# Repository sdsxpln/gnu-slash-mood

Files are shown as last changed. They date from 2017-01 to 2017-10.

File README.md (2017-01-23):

GNU/Mood: An IoT mood indicator for GNU Social
==============================================

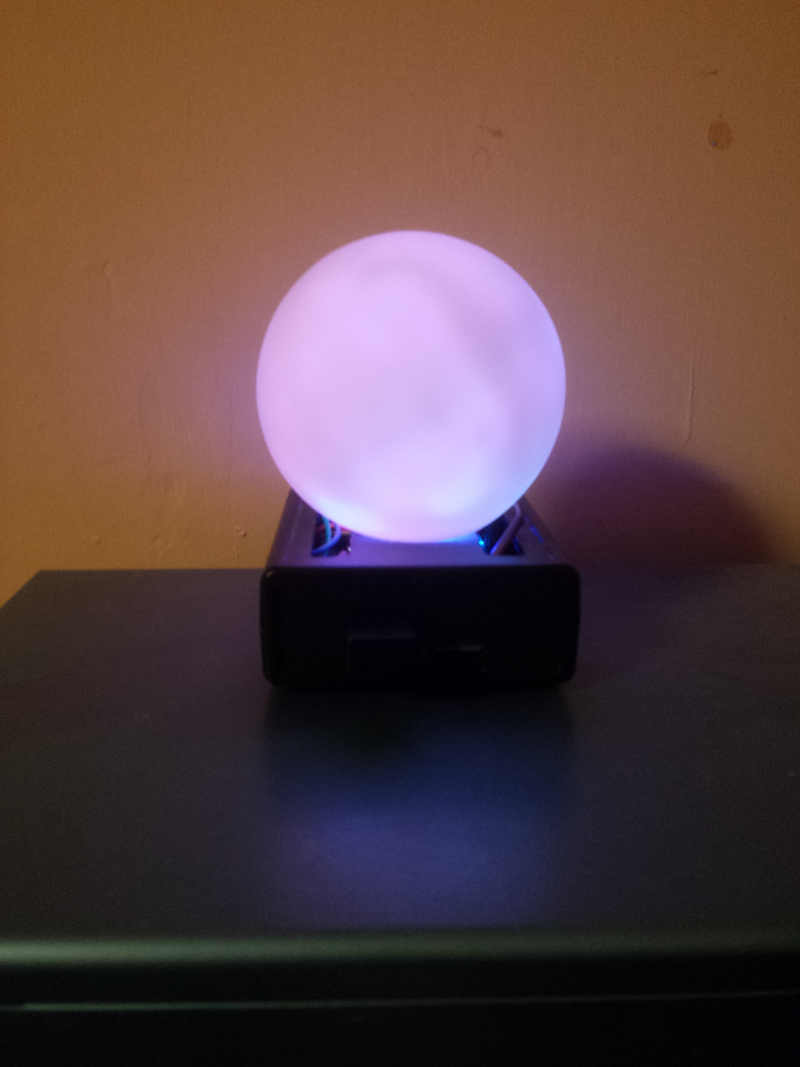
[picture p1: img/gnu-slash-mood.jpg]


GNU/Mood is a mood ball hack where the colour LEDs are controlled by sentiment analysis of your GNU Social timeline. It reads the last few entries in your timeline and extracts three mood dimensions:

 - Egocentrism: Talk about yourself versus talk about others
 - Valence: An indicator of positive or negative affect. Happyness or sadness.
 - Gender: Feminine or masculine related words or names

These measures are then turned into LED illumination values to produce the colour of the ball, which changes slowly and almost imperceptibly.

GNU/Mood can also be "triggered" if it detects certain key words within the timeline. This causes it to pulsate slowly and soothingly, guiding the user into a more blissful state of mind.

Bill of Materials
=================

    1 x Beaglebone Black (wireless or with a compatible wifi dongle)
    1 x Beaglebone Black case (Choose your favourite or 3D print one)
    1 x micro/mini USB cable (the type which usually comes with a Beaglebone Black)
    1 x 5V 2A power supply for the Beaglebone Black
    6 x Dupont Cables male to female Jumper GPIO Wire Ribbon
    1 x Ultrabright 3V red LED
    1 x Ultrabright 3V green LED
    1 x Ultrabright 3V blue LED
    1 x LED Mood Ball Lamp
    1 x microSD card (8GB or larger, class 10)
    1 x Small amount of bubble wrap packing plastic
    1 x Superglue

Tools
=====

    Precision screwdrivers
    Junior hacksaw
    Pliers
    Drill

Wiring
======

Connecting the LEDs to the Beaglebone Black is very simple and no resistors should be needed. You can either solder the LEDs to the dupont cables, or just inserting them into the female sockets is usually good enough.

    Red    P8/13
    Green  P9/14
    Blue   P8/19

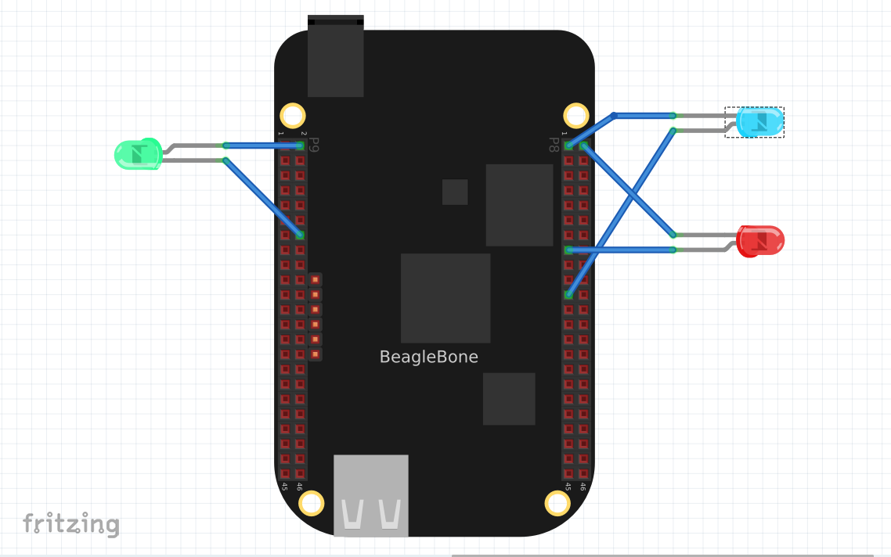
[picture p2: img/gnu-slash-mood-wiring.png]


Preparing the Mood Ball
=======================

Use a precision screwdriver to remove the batteries from the Mood ball.



With a junior hacksaw cut around the bottom of the mood ball to loosen the electronics section. Make sure not to scratch the surface of the rest of the ball. Once it's loose enough it can be carefully pulled out with pliers.



The existing electronics aren't needed, but you may wish to salvage the LEDs from it by desoldering them. For an easy life, just use new LEDs if you have them available. They should be the ultra bright type and any physical size will do.

Installing the Software
=======================

The Beaglebone Black comes with an existing operating system installed, but the 4GB onboard flash storage may not be enough for the new software and so it's better to install the operating system onto a microSD card instead.

Download the latest [Debian firmware image](http://beagleboard.org/latest-images) and copy it to the microSD card. The command will be something like:

``` bash
sudo dd if=[image filename] of=/dev/sdX
sync
```

Where *sdX* is the microSD drive on your laptop/desktop. You can find out what this should be just by removing the microSD card then running:

``` bash
ls /dev/sd*
```

Then inserting the microSD card and running the same command again. Typically this will be *sdb*, *sdc*, *sdd*, etc. Once that has coppied insert the card into the Beaglebone Black and connect it to your laptop/desktop with the USB cable. If you're using an external wifi dongle then also plug that into the Beaglebone Black. After a few minutes you will then be able to ssh into the Beaglebone Black with:

``` bash
ssh debian@192.168.7.2
```

The initial temporary password is usually *temppwd*. Change it with the command:

``` bash
passwd
```

Then set up the wifi connection with:

``` bash
sudo connmanctl
connmanctl> technologies
connmanctl> tether wifi disable
connmanctl> enable wifi
connmanctl> scan wifi
connmanctl> services
connmanctl> agent on
connmanctl> connect wifi_[somenumbers]
connmanctl> quit
```

If the connect command worked then your Beaglebone is now ready for wireless operation. Disconnect the USB cable and plug in the external 5V power supply. After a few minutes once it has booted again you can ssh back into it with:

``` bash
ssh debian@beaglebone.local
```

Note that you will need to have avahi/mDNS configured on your system to be able to do this. Now run:

``` bash
sudo apt-get update
sudo apt-get upgrade
sudo apt-get -y install build-essential git curl libcurl4-openssl-dev ntp
git clone https://github.com/bashrc/libbbb
git clone https://github.com/bashrc/libgnusocial
git clone https://github.com/bashrc/gnu-slash-mood
cd libbbb
make
sudo make install
cd ../libgnusocial
make
sudo make install
cd ../gnu-slash-mood
make
sudo make install
sudo cp daemons/gnu-slash-mood.service /etc/systemd/system
sudo mkdir /var/lib/gnu-slash-mood
sudo nano /var/lib/gnu-slash-mood/config.txt
```

Add the following, setting your details as needed. The *off* and *on* values are the hours of the day when GNU/Mood should turn off and then turn on again so as not to disturb sleep (0 is midnight).

    username = [myusername]
    password = [password]
    domain = [GNU Social domain]
    off = 0
    on = 7

Now enable the daemon:

``` bash
sudo systemctl enable gnu-slash-mood
sudo systemctl start gnu-slash-mood
```

You can check that the daemon started correctly with:

``` bash
sudo systemctl status gnu-slash-mood -l
```

Once the software is running you should see that the LEDs initially flash and then transition to a stable colour.

Final Assembly
==============

Mount the Beaglebone Black into its case. Usually it's fastened down with four screws.

Drill three (or as many as needed) holes into the top of the case so that the LEDs can poke through. One possible way to do it is with six small holes which then fit the LED terminals.

Scrumple up the bubble wrap and put it inside the mood ball. The bubbles will cause light from the LEDs to be diffracted in all directions, giving a more uniform colour and avoiding any isolated spots of colour.

Fit the top of the case to the bottom, then place the mood ball over the LEDs. Check that it illuminates as expected.

Glue the mood ball to the top of the case with some superglue.

GNU/Mood is now ready for moodyness.

Security Tips
=============

Everyone is paranoid about the *internet of hopelessly insecure things*. To improve the security of GNU/Mood you can do the following:

``` bash
ssh debian@beaglebone.local
sudo nano /etc/ssh/sshd_config
```

Set the following:

    PermitRootLogin no
    PermitEmptyPasswords no

And if you are using *~/.ssh/authorized_keys* then set:

    PasswordAuthentication no

Save and reboot the Beaglebone.

Custom Trigger Words
====================

You can customise the words which cause GNU/Mood to pulsate.

``` bash
ssh debian@beaglebone.local
sudo nano /var/lib/gnu-slash-mood/triggers.txt
```

An example *triggers.txt* file might look like:

``` text
stallman
systemd
DRM
#NSFW
proprietary
```

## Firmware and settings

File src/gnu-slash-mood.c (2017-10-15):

/*
    GNU/Mood: A mood indicator for GNU Social
    Copyright (C) 2017 Bob Mottram
    bob@freedombone.net

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
    You should have received a copy of the GNU General Public License
    along with this program.  If not, see <http://www.gnu.org/licenses/>.
*/

#include <time.h>
#include "gnu-slash-mood.h"

/* The maximum number of characters obtained from the timeline */
#define MAX_TEXT_LENGTH    (1024*4)

/* Check the timeline every few minutes */
#define CHECK_TIMELINE_SEC (60 * 5)

/* whether to show a test pattern */
unsigned char use_test_pattern = 0;

/* whether to enable debugging output */
unsigned char debug = 0;

/* login details */
char gnusocial_username[512];
char gnusocial_password[512];
char gnusocial_domain_name[512];

/* time to turn off and on again */
unsigned char hour_off = 0;
unsigned char hour_on = 7;

struct gss_account acc;

/**
 * @brief Show help
 */
void show_help()
{
    printf("\nGNU/Mood: The mood of the community\n\n");
    printf("Pinout: Red P8/13, Green P9/14, Blue P8/19\n\n");
    printf(" -h --help              Show help\n");
    printf(" -u --username [name]   Username\n");
    printf(" -d --domain [name]     Site domain name\n");
    printf(" -p --password [text]   Password\n\n");
    printf(" -t --test              Test mode\n");
    printf(" -c --config [filename] Read login details from file\n");
    printf("    --off [hour]        Hour when to turn off\n");
    printf("    --on [hour]         Hour when to turn on\n");
    printf("    --debug             Enable debugging output\n\n");
}

/**
 * @brief Returns 1 if the mood ball should be active
 */
int is_active()
{
    int state = 1;
    time_t t = time(NULL);
    struct tm *tmp = gmtime(&t);

    if (hour_off > hour_on) {
        if ((int)tmp->tm_hour > (int)hour_off)
            state = 0;
        if ((int)tmp->tm_hour < (int)hour_on)
            state = 0;
    }
    else {
        if (((int)tmp->tm_hour >= (int)hour_off) &&
            ((int)tmp->tm_hour < (int)hour_on))
            state = 0;
    }

    return state;
}

/**
 * @brief Reads an individual line from the config file
 * @param linestr The line of text
 * @param Returned parameter value
 * @return Zero on success
 */
int read_login_param(char * linestr, char * paramstr)
{
    int i, j;

    for (i = 0; i < strlen(linestr); i++) {
        if ((linestr[i] == '=') || (linestr[i] == ':')) break;
    }

    if (i == strlen(linestr))
        return 1;

    /* skip any spaces or tabs */
    i++;
    while (((linestr[i] == ' ') || (linestr[i] == '\t')) &&
           (i < strlen(linestr)-1))
        i++;

    j = 0;
    while (i < strlen(linestr)) {
        if ((linestr[i] != 10) && (linestr[i] != 13))
            paramstr[j++] = linestr[i];
        i++;
    }
    paramstr[j] = 0;

    return 0;
}

int read_login_credentials(char * config_filename)
{
    FILE * fp;
    char linestr[512], paramstr[512];

    /* clear login credentials */
    gnusocial_username[0] = 0;
    gnusocial_password[0] = 0;
    gnusocial_domain_name[0] = 0;

    fp = fopen(config_filename, "r");
    if (!fp) return 1;

    while (!feof(fp)) {
        if (fgets(linestr , 511 , fp) != NULL ) {
            if (strlen(linestr) == 0) continue;
            if (linestr[0] == '#') continue;

            linestr[0] = tolower(linestr[0]);
            if ((strstr(linestr,"username =") != NULL) ||
                (strstr(linestr,"username :") != NULL) ||
                (strstr(linestr,"username:") != NULL) ||
                (strstr(linestr,"username=") != NULL)) {
                if (read_login_param(linestr, paramstr) != 0)
                    return 2;
                sprintf(gnusocial_username, "%s", paramstr);
            }

            if ((strstr(linestr,"password =") != NULL) ||
                (strstr(linestr,"password :") != NULL) ||
                (strstr(linestr,"password:") != NULL) ||
                (strstr(linestr,"password=") != NULL)) {
                if (read_login_param(linestr, paramstr) != 0)
                    return 3;
                sprintf(gnusocial_password, "%s", paramstr);
            }

            if ((strstr(linestr,"domain =") != NULL) ||
                (strstr(linestr,"domain :") != NULL) ||
                (strstr(linestr,"domain:") != NULL) ||
                (strstr(linestr,"domain=") != NULL)) {
                if (read_login_param(linestr, paramstr) != 0)
                    return 4;
                sprintf(gnusocial_domain_name, "%s", paramstr);
            }

            if ((strstr(linestr,"off =") != NULL) ||
                (strstr(linestr,"off :") != NULL) ||
                (strstr(linestr,"off:") != NULL) ||
                (strstr(linestr,"off=") != NULL)) {
                if (read_login_param(linestr, paramstr) != 0)
                    return 5;
                hour_off = (unsigned char)atoi(paramstr);
            }

            if ((strstr(linestr,"on =") != NULL) ||
                (strstr(linestr,"on :") != NULL) ||
                (strstr(linestr,"on:") != NULL) ||
                (strstr(linestr,"on=") != NULL)) {
                if (read_login_param(linestr, paramstr) != 0)
                    return 6;
                hour_on = (unsigned char)atoi(paramstr);
            }
        }
    }

    fclose(fp);

    if ((strlen(gnusocial_username) == 0) ||
        (strlen(gnusocial_password) == 0) ||
        (strlen(gnusocial_domain_name) == 0))
        return 7;

    return 0;
}

int set_leds(int r, int g, int b)
{
    if (pwm_output(P8, 13, r) != 0) return 1;
    if (pwm_output(P9, 14, g) != 0) return 2;
    if (pwm_output(P8, 19, b) != 0) return 3;
    return 0;
}

int get_timeline_text(char * text)
{
    struct status * posts;
    const int no_of_posts = 5;
    int i, j, ctr=0;

    if (verify_account(acc) == -1) return 1;
    posts = read_timeline(acc, HOME_TIMELINE, no_of_posts);
    for (i = 0; i < no_of_posts; i++) {
        for (j = 0; j < strlen(posts[i].text); j++) {
            if (ctr >= MAX_TEXT_LENGTH-1) {
                text[ctr]=0;
                return 0;
            }
            text[ctr++] = posts[i].text[j];
        }
        text[ctr++] = '.';
    }
    text[ctr]=0;
    return 0;
}

int mood_loop()
{
    int curr_r=0, curr_g=0, curr_b=0;
    int target_r, target_g, target_b, frequency = 0;
    int ctr_msec=0, phase = 0, intensity = 100, state = 0;
    char text[MAX_TEXT_LENGTH];

    if (get_timeline_text(text) != 0) {
        printf("Failed to grab text from the timeline\n");
        return 1;
    }

    printf("GNU Social login success\n");

    if (use_test_pattern == 0) {
        sentiment_to_rgb(text, &curr_r, &curr_g, &curr_b, &frequency);
        target_r = curr_r;
        target_g = curr_g;
        target_b = curr_b;
    }
    else
        printf("Running test pattern\n");

    if (set_leds(curr_r, curr_g, curr_b) != 0) {
        printf("Unable to set LED pwm values\n");
        return 2;
    }

    while(1) {
        if (is_active() == 0) {
            /* fade out */
            target_r = 0;
            target_g = 0;
            target_b = 0;
        }

        /* shift the colour towards the target */
        if (target_r > curr_r) curr_r++;
        if (target_g > curr_g) curr_g++;
        if (target_b > curr_b) curr_b++;

        if (target_r < curr_r) curr_r--;
        if (target_g < curr_g) curr_g--;
        if (target_b < curr_b) curr_b--;

        if (use_test_pattern != 0) {
            if (curr_r < 1000)
                curr_r += 100;
            else
                if (curr_b < 1000)
                    curr_b += 100;
                else
                    if (curr_g < 1000)
                        curr_g += 100;
                    else {
                        curr_r = 0;
                        curr_b = 0;
                        curr_g = 0;
                    }
        }

        if (debug != 0)
            printf("Active: %d  Colour: %d %d %d  Intensity: %d  Frequency: %d\n",
                   is_active(), curr_r, curr_g, curr_b, intensity, frequency);

        if (set_leds(curr_r*intensity/100,
                     curr_g*intensity/100,
                     curr_b*intensity/100) != 0) {
            printf("Unable to set LED pwm values\n");
        }

        if (ctr_msec >= CHECK_TIMELINE_SEC*1000) {
            ctr_msec = 0;

            if (is_active() == 1) {
                /* update the timeline */
                if (get_timeline_text(text) != 0) {
                    printf("Failed to grab text from the timeline\n");
                }
                else {
                    /* calculate the new target colour */
                    sentiment_to_rgb(text, &target_r, &target_g, &target_b, &frequency);
                    if (debug != 0)
                        printf(">>>> Updated from timeline <<<<\n");
                }
            }
        }

        /* wait */
        usleep(1000*100);
        fflush(stdout);

        ctr_msec += 100;
        if (frequency != 0) {
            if (state == 0) {
                intensity -= 70/(frequency/2);
                if (phase > frequency/2) {
                    state = 1;
                }
            }
            else {
                intensity += 70/(frequency/2);
                if (phase > frequency) {
                    state = 0;
                    phase = 0;
                    intensity = 100;
                }
            }
            if (intensity > 100) intensity = 100;
            if (intensity < 30) intensity = 30;
            phase++;
        }
        else {
            intensity = 100;
            phase = 0;
            state = 0;
        }
    }
    return 0;
}

int main(int argc, char *argv[])
{
    int i;
    char username[1024], domain_name[1024], password[1024];

    /* clear login values */
    username[0] = 0;
    domain_name[0] = 0;
    password[0] = 0;

    /* parse the arguments */
    for (i = 1; i < argc; i++) {
        if (i < argc-1) {
            if ((strcmp(argv[i], "-u") == 0) ||
                (strcmp(argv[i], "--user") == 0) ||
                (strcmp(argv[i], "--username") == 0)) {
                sprintf(username, "%s", argv[i+1]);
                i++;
                continue;
            }

            if ((strcmp(argv[i], "-d") == 0) ||
                (strcmp(argv[i], "--domain") == 0) ||
                (strcmp(argv[i], "--domainname") == 0)) {
                sprintf(domain_name, "%s", argv[i+1]);
                i++;
                continue;
            }

            if ((strcmp(argv[i], "-p") == 0) ||
                (strcmp(argv[i], "--password") == 0) ||
                (strcmp(argv[i], "--passphrase") == 0)) {
                sprintf(password, "%s", argv[i+1]);
                i++;
                continue;
            }

            if ((strcmp(argv[i], "-c") == 0) ||
                (strcmp(argv[i], "--config") == 0)) {
                if (read_login_credentials(argv[i+1]) == 0) {
                    sprintf(username, "%s", gnusocial_username);
                    sprintf(password, "%s", gnusocial_password);
                    sprintf(domain_name, "%s", gnusocial_domain_name);
                }
                else {
                    printf("Invalid configuration file\n");
                    return 4;
                }
                i++;
                continue;
            }

            if (strcmp(argv[i], "--off") == 0) {
                hour_off = (unsigned char)atoi(argv[i+1]);
                i++;
                continue;
            }

            if (strcmp(argv[i], "--on") == 0) {
                hour_on = (unsigned char)atoi(argv[i+1]);
                i++;
                continue;
            }
        }

        if ((strcmp(argv[i], "-h") == 0) ||
            (strcmp(argv[i], "--help") == 0)) {
            show_help();
            return 0;
        }

        if ((strcmp(argv[i], "-t") == 0) ||
            (strcmp(argv[i], "--test") == 0))
            use_test_pattern = 1;

        if (strcmp(argv[i], "--debug") == 0)
            debug = 1;
    }

    if (argc <= 1) {
        show_help();
        return 0;
    }

    if (strlen(username) == 0) {
        printf("Please specify a GNU Social username\n");
        return 1;
    }
    if (strlen(domain_name) == 0) {
        printf("Please specify a GNU Social domain name\n");
        return 2;
    }
    if (strlen(password) == 0) {
        printf("Please specify a GNU Social password\n");
        return 3;
    }

    init_account(&acc, "https", (char*)username, (char*)domain_name, (char*)password);
    mood_loop();

    return 0;
}

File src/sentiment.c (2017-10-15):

/*
  GNU/Mood: A mood indicator for GNU Social
  Copyright (C) 2017 Bob Mottram
  bob@freedombone.net

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
  You should have received a copy of the GNU General Public License
  along with this program.  If not, see <http://www.gnu.org/licenses/>.
*/

#include "gnu-slash-mood.h"

/* Note: All words should be in lower case */

/*
  Words from AFINN-111 under Open Database License (ODbL) v1.0
  http://www2.imm.dtu.dk/pubdb/views/publication_details.php?id=6010
  http://www.opendatacommons.org/licenses/odbl/1.0/
*/

char * sentiment_word_en[] = {
    "abandon","abandoned","abandons","abducted","abduction","abductions","abhor","abhorred","abhorrent","abhors","abilities","ability","aboard","absentee","absentees","absolve","absolved","absolves","absolving","absorbed","abuse","abused","abuses","abusive","accept","accepted","accepting","accepts","accident","accidental","accidentally","accidents","accomplish","accomplished","accomplishes","accusation","accusations","accuse","accused","accuses","accusing","ache","achievable","aching","acquit","acquits","acquitted","acquitting","acrimonious","active","adequate","admire","admired","admires","admiring","admit","admits","admitted","admonish","admonished","adopt","adopts","adorable","adore","adored","adores","advanced","advantage","advantages","adventure","adventures","adventurous","affected","affection","affectionate","afflicted","affronted","afraid","aggravate","aggravated","aggravates","aggravating","aggression","aggressions","aggressive","aghast","agog","agonise","agonised","agonises","agonising","agonize","agonized","agonizes","agonizing","agree","agreeable","agreed","agreement","agrees","alarm","alarmed","alarmist","alarmists","alas","alert","alienation","alive","allergic","allow","alone","amaze","amazed","amazes","amazing","ambitious","ambivalent","amuse","amused","amusement","amusements","anger","angers","angry","anguish","anguished","animosity","annoy","annoyance","annoyed","annoying","annoys","antagonistic","anti","anticipation","anxiety","anxious","apathetic","apathy","apeshit","apocalyptic","apologise","apologised","apologises","apologising","apologize","apologized","apologizes","apologizing","apology","appalled","appalling","appease","appeased","appeases","appeasing","applaud","applauded","applauding","applauds","applause","appreciate","appreciated","appreciates","appreciating","appreciation","apprehensive","approval","approved","approves","ardent","arrest","arrested","arrests","arrogant","ashame","ashamed","ass","assassination","assassinations","asset","assets","assfucking","asshole","astonished","astound","astounded","astounding","astoundingly","astounds","attack","attacked","attacking","attacks","attract","attracted","attracting","attraction","attractions","attracts","audacious","authority","avert","averted","averts","avid","avoid","avoided","avoids","await","awaited","awaits","award","awarded","awards","awesome","awful","awkward","axe","axed","backed","backing","backs","bad","badass","badly","bailout","bamboozle","bamboozled","bamboozles","ban","banish","bankrupt","bankster","banned","bargain","barrier","bastard","bastards","battle","battles","beaten","beatific","beating","beauties","beautiful","beautifully","beautify","belittle","belittled","beloved","benefit","benefits","benefitted","benefitting","bereave","bereaved","bereaves","bereaving","best","betray","betrayal","betrayed","betraying","betrays","better","bias","biased","big","bitch","bitches","bitter","bitterly","bizarre","blah","blame","blamed","blames","blaming","bless","blesses","blessing","blind","bliss","blissful","blithe","block","blockbuster","blocked","blocking","blocks","bloody","blurry","boastful","bold","boldly","bomb","boost","boosted","boosting","boosts","bore","bored","boring","bother","bothered","bothers","bothersome","boycott","boycotted","boycotting","boycotts","brainwashing","brave","breakthrough","breathtaking","bribe","bright","brightest","brightness","brilliant","brisk","broke","broken","brooding","bullied","bullshit","bully","bullying","bummer","buoyant","burden","burdened","burdening","burdens","calm","calmed","calming","calms","can't stand","cancel","cancelled","cancelling","cancels","cancer","capable","captivated","care","carefree","careful","carefully","careless","cares","cashing in","casualty","catastrophe","catastrophic","cautious","celebrate","celebrated","celebrates","celebrating","censor","censored","censors","certain","chagrin","chagrined","challenge","chance","chances","chaos","chaotic","charged","charges","charm","charming","charmless","chastise","chastised","chastises","chastising","cheat","cheated","cheater","cheaters","cheats","cheer","cheered","cheerful","cheering","cheerless","cheers","cheery","cherish","cherished","cherishes","cherishing","chic","childish","chilling","choke","choked","chokes","choking","clarifies","clarity","clash","classy","clean","cleaner","clear","cleared","clearly","clears","clever","clouded","clueless","cock","cocksucker","cocksuckers","cocky","coerced","collapse","collapsed","collapses","collapsing","collide","collides","colliding","collision","collisions","colluding","combat","combats","comedy","comfort","comfortable","comforting","comforts","commend","commended","commit","commitment","commits","committed","committing","compassionate","compelled","competent","competitive","complacent","complain","complained","complains","comprehensive","conciliate","conciliated","conciliates","conciliating","condemn","condemnation","condemned","condemns","confidence","confident","conflict","conflicting","conflictive","conflicts","confuse","confused","confusing","congrats","congratulate","congratulation","congratulations","consent","consents","consolable","conspiracy","constrained","contagion","contagions","contagious","contempt","contemptuous","contemptuously","contend","contender","contending","contentious","contestable","controversial","controversially","convince","convinced","convinces","convivial","cool","cool
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

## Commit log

2017-01-23 Add superglue to the bom
2017-01-23 Keep track of time
2017-01-23 Convert custom trigger words to lower case

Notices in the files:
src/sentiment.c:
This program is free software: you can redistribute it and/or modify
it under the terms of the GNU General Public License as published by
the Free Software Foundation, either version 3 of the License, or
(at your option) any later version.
